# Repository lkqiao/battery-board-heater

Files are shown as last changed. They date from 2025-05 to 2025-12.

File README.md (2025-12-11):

# battery-board-heater
Subproject as part of the Stanford Student Space Initiative (SSI). This project provides the heater circuit used for the battery board of SAMWISE, the 2U CubeSat we are currently working on, to maintain optimal temperature for efficient auxiliary power supply to deployable structures, ADCS, radio, and a 12MP camera + selfie stick. 

The schematic of the heater circuit is provided in KiCAD and is integrated into the main battery board PCB and external systems of the satellite. The coordinates of the heating coil traces are automatically generated via Python script. 

Screenshot 2025-12-11 at 12 20 15 PM

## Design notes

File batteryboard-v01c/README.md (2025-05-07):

# PyCubed Battery Board

<p align="middle">
  
</p>

2S3P Li-ion battery pack for CubeSat designs.
   - Fits 18650 cells (like the LG INR18650-MJ1)
   - Meets maximum capacity requirements of common CubeSat integrators
   - Uses components with radiation testing heritage
      - R5460x2xx for protection against
         - over-charge 
         - over-discharge
         - short-circuit
         - excess discharge-current
         - excess charge-current

## Interactive Bill of Materials 🛒
- [batteryboard-v01](https://pycubed.github.io/hardware/batteryboard-v01)

<br>
<br>
<br>
<br />This work is licensed under a <a rel="license" href="http://creativecommons.org/licenses/by/4.0/">Creative Commons Attribution 4.0 International License</a>.

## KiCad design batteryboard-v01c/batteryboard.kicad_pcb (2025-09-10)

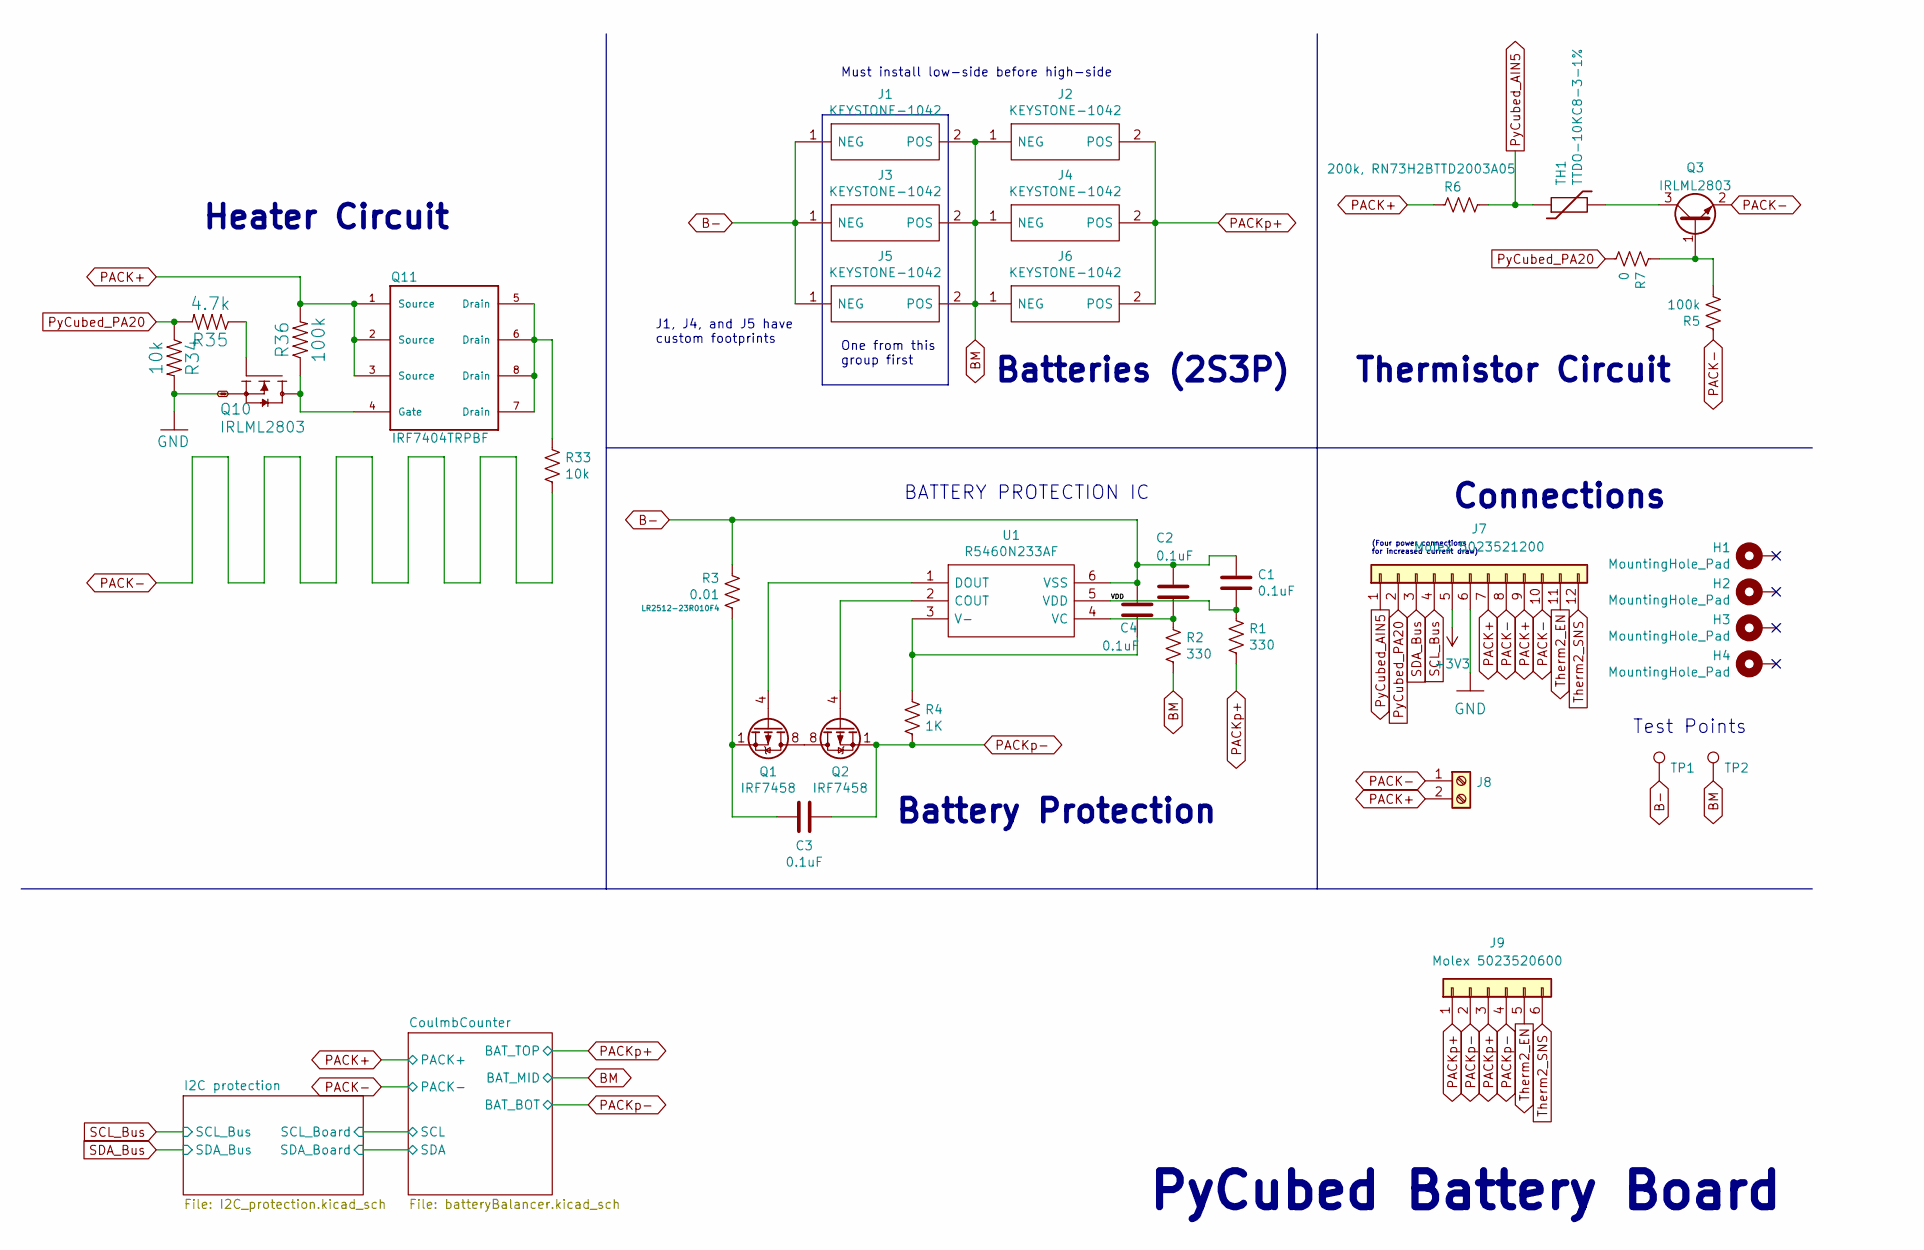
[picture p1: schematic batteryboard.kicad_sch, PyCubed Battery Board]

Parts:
C1, C2, C3, C4: 0.1uF; C_0603_1608Metric
H1, H2, H3, H4: MountingHole_Pad; MountingHole_3.2mm_M3_DIN965_PadMOD
J1: KEYSTONE-1042; Keystone_1042_J1; Manufacturer_Part_Number 1042; Mouser Part Number 534-1042
J2, J3, J6: KEYSTONE-1042; Keystone_1042; Manufacturer_Part_Number 1042; Mouser Part Number 534-1042
J4: KEYSTONE-1042; Keystone_1042_J4; Manufacturer_Part_Number 1042; Mouser Part Number 534-1042
J5: KEYSTONE-1042; Keystone_1042_J5; Manufacturer_Part_Number 1042; Mouser Part Number 534-1042
J7: Molex 5023521200; 5023521200
J8: Screw_Terminal_01x02; pheonix_2pos_screwterminal
J9: Molex 5023520600; 5023520600
Q1, Q2: IRF7458; SOIC-8_3.9x4.9mm_P1.27mm
Q3: IRLML2803; SOT-23
Q10: IRLML2803; SOT-23; Manufacturer_Part_Number MMBT2222AT
Q11: IRF7404TRPBF; Manufacturer_Part_Number NDS8434
R1, R2: 330; R_0603_1608Metric
R3: 0.01; R_2512_6332Metric
R4: 1K; R_0603_1608Metric; Manufacturer_Part_Number LR2512-23R010F4
R5, R36: 100k; R_0603_1608Metric
R6: 200k, RN73H2BTTD2003A05; R_1206_3216Metric
R7: 0; R_0603_1608Metric
R33, R34: 10k; R_0603_1608Metric
R35: 4.7k; R_0603_1608Metric
TH1: TTDO-10KC8-3-1%; R_Axial_DIN0204_L3.6mm_D1.6mm_P5.08mm_Horizontal
TP1, TP2: TestPoint; TestPoint_Loop_D1.80mm_Drill1.0mm_Beaded
U1: R5460N233AF; SOT-23-6; Manufacturer_Part_Number R5460N233AF-TR-FE; Mouser Part Number 848-R5460N233AFTRFE

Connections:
+3V3: J7.5; also elsewhere on the board
/VDD: C1.2, R1.2, U1.5 (VDD)
B-: C1.1, C2.1, C4.1, J1.1 (NEG), J3.1 (NEG), J5.1 (NEG), R3.1, TP1.1, U1.6 (VSS)
BM: J1.2 (POS), J2.1 (NEG), J3.2 (POS), J4.1 (NEG), J5.2 (POS), J6.1 (NEG), R2.1, TP2.1; also elsewhere on the board
GND: J7.6, Q10.2 (S), R34.2; also elsewhere on the board
unnamed: C3.1, Q1.1 (S), Q1.2 (S), Q1.3 (S), R3.2
unnamed: Q1.5 (D), Q1.6 (D), Q1.7 (D), Q1.8 (D), Q2.5 (D), Q2.6 (D), Q2.7 (D), Q2.8 (D)
unnamed: Q1.4 (G), U1.1 (DOUT)
unnamed: Q2.4 (G), U1.2 (COUT)
unnamed: Q3.1 (B), R5.1, R7.2
unnamed: Q3.3 (C), TH1.2
unnamed: Q10.3 (D), Q11.4 (Gate), R36.1
unnamed: Q10.1 (G), R35.1
unnamed: Q11.5 (Drain), Q11.6 (Drain), Q11.7 (Drain), Q11.8 (Drain), R33.2
unnamed: C4.2, R4.1, U1.3 (V-)
unnamed: C2.2, R2.2, U1.4 (VC)
PACK+: J7.7, J7.9, J8.2, Q11.1 (Source), Q11.2 (Source), Q11.3 (Source), R6.1, R36.2; also elsewhere on the board
PACK-: J7.8, J7.10, J8.1, Q3.2 (E), R5.2, R33.1; also elsewhere on the board
PACKp+: J2.2 (POS), J4.2 (POS), J6.2 (POS), J9.1, J9.3, R1.1; also elsewhere on the board
PACKp-: C3.2, J9.2, J9.4, Q2.1 (S), Q2.2 (S), Q2.3 (S), R4.2; also elsewhere on the board
PyCubed_AIN5: J7.1, R6.2, TH1.1
PyCubed_PA20: J7.2, R7.1, R34.1, R35.2
SCL_Bus: J7.4; also elsewhere on the board
SDA_Bus: J7.3; also elsewhere on the board
Therm2_EN: J7.11, J9.5
Therm2_SNS: J7.12, J9.6

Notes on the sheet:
Connections
(Four power connections for increased current draw)
One from this group first
PyCubed Battery Board
Batteries (2S3P)
Heater Circuit
Test Points
J1, J4, and J5 have custom footprints
Battery Protection
Must install low-side before high-side
Thermistor Circuit
BATTERY PROTECTION IC

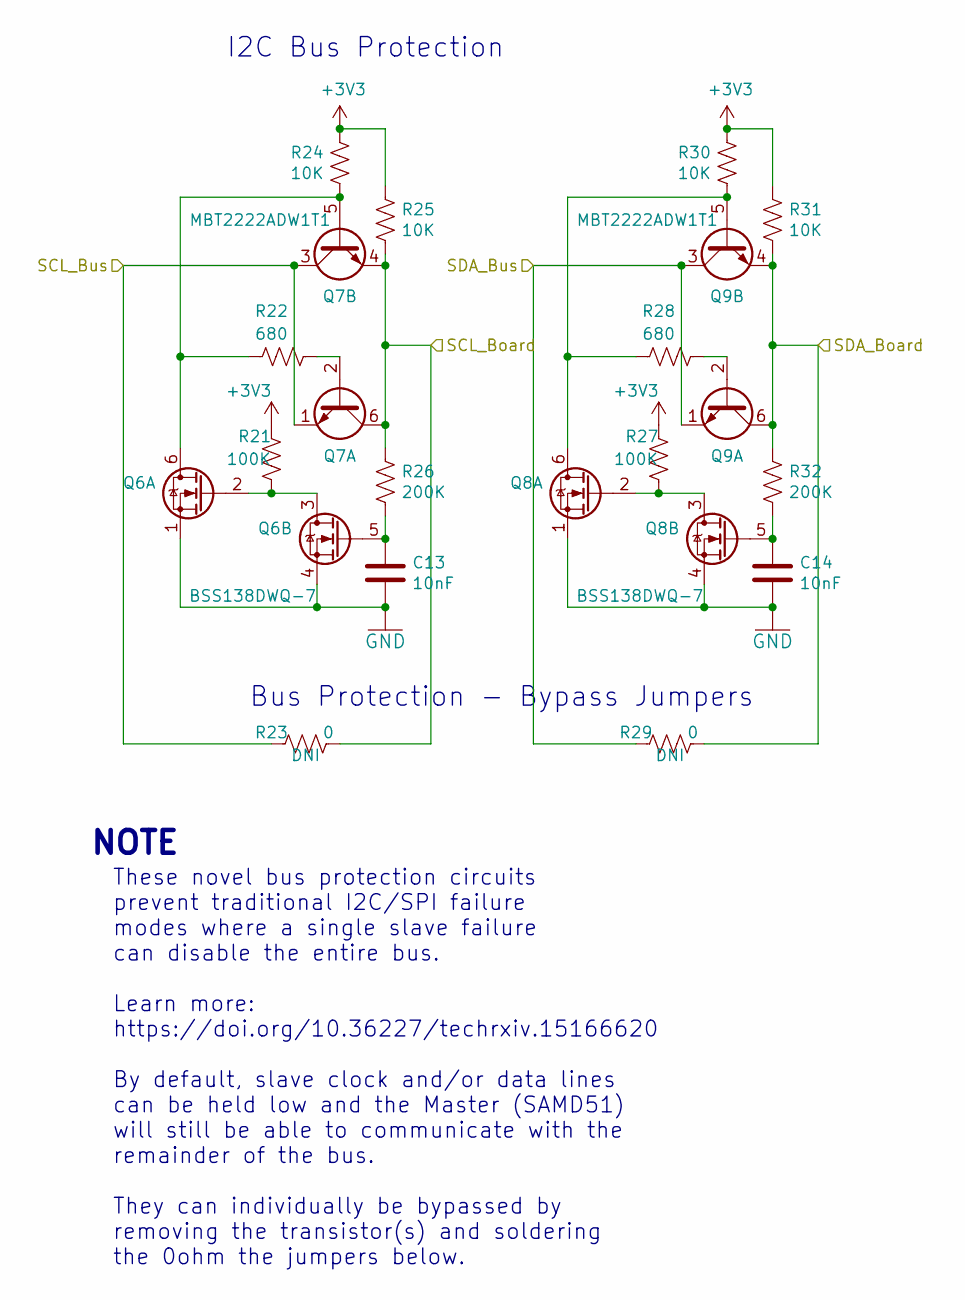
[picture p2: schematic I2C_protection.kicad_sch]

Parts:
C13, C14: 10nF; C_0603_1608Metric
Q6, Q8: BSS138DWQ-7; Manufacturer_Part_Number BSS138DWQ-7; Mouser Part Number 621-BSS138DWQ-7
Q7, Q9: MBT2222ADW1T1; SOT-363_SC-70-6; Manufacturer_Part_Number MBT2222ADW1T1G
R21, R27: 100K; R_0603_1608Metric
R22, R28: 680; R_0603_1608Metric
R23, R29: 0; R_0603_1608Metric
R24, R25, R30, R31: 10K; R_0603_1608Metric
R26, R32: 200K; R_0603_1608Metric

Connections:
+3V3: R21.1, R24.1, R25.1, R27.1, R30.1, R31.1; also elsewhere on the board
/CoulmbCounter/SCL: Q7.4 (E2), Q7.6 (C1), R23.1, R25.2, R26.1; also elsewhere on the board
/CoulmbCounter/SDA: Q9.4 (E2), Q9.6 (C1), R29.1, R31.2, R32.1; also elsewhere on the board
GND: C13.2, C14.2, Q6.1 (S2), Q6.4 (S1), Q8.1 (S2), Q8.4 (S1); also elsewhere on the board
unnamed: Q6.6 (D1), Q7.5 (B2), R22.2, R24.2
unnamed: Q6.2 (G2), Q6.3 (D2), R21.2
unnamed: C13.1, Q6.5 (G1), R26.2
unnamed: Q7.2 (B1), R22.1
unnamed: Q8.6 (D1), Q9.5 (B2), R28.2, R30.2
unnamed: Q8.2 (G2), Q8.3 (D2), R27.2
unnamed: C14.1, Q8.5 (G1), R32.2
unnamed: Q9.2 (B1), R28.1
SCL_Bus: Q7.1 (E1), Q7.3 (C2), R23.2; also elsewhere on the board
SDA_Bus: Q9.1 (E1), Q9.3 (C2), R29.2; also elsewhere on the board

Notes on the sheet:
NOTE
These novel bus protection circuits prevent traditional I2C/SPI failure modes where a single slave failure can disable the entire bus. Learn more: https://doi.org/10.36227/techrxiv.15166620 By default, slave clock and/or data lines can be held low and the Master (SAMD51) will still be able to commu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
Bus Protection - Bypass Jumpers
I2C Bus Protection

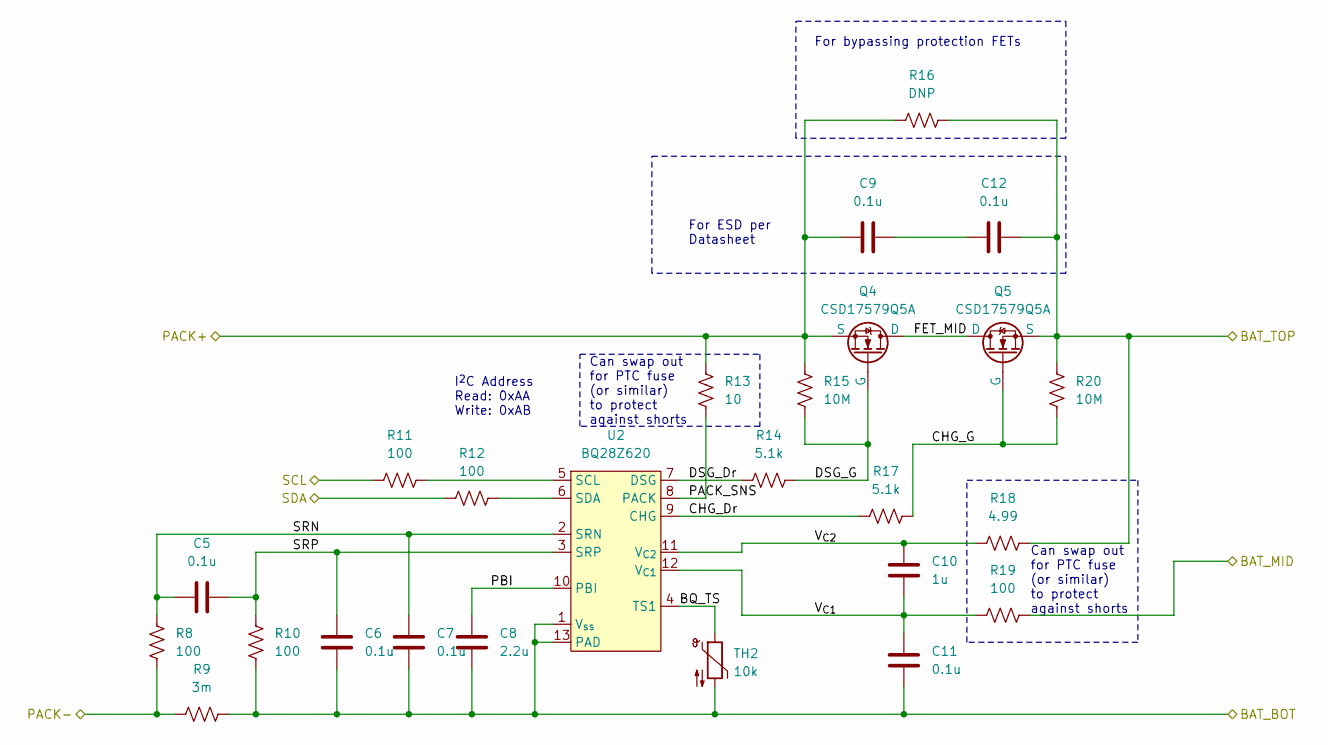
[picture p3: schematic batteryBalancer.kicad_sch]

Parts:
C5, C6, C7, C9, C11, C12: 0.1u; C_0603_1608Metric
C8: 2.2u; C_0603_1608Metric
C10: 1u; C_0603_1608Metric
Q4, Q5: CSD17579Q5A; DQJ8_NMOS_DGS
R8, R10, R11, R12, R19: 100; R_0603_1608Metric
R9: 3m; R_1206_3216Metric
R13: 10; R_0603_1608Metric
R14, R17: 5.1k; R_0603_1608Metric
R15, R20: 10M; R_0603_1608Metric
R16: DNP; R_1206_3216Metric
R18: 4.99; R_0603_1608Metric
TH2: 10k; R_Axial_DIN0204_L3.6mm_D1.6mm_P5.08mm_Horizontal
U2: BQ28Z620; VSON12_DRZ_TEX

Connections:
/CoulmbCounter/BQ_TS: TH2.1, U2.4 (TS1)
/CoulmbCounter/CHG_Dr: R17.1, U2.9 (CHG)
/CoulmbCounter/CHG_G: Q5.2 (G), R17.2, R20.2
/CoulmbCounter/DSG_Dr: R14.1, U2.7 (DSG)
/CoulmbCounter/DSG_G: Q4.2 (G), R14.2, R15.2
/CoulmbCounter/FET_MID: Q4.1 (D), Q5.1 (D)
/CoulmbCounter/PACK_SNS: R13.2, U2.8 (PACK)
/CoulmbCounter/PBI: C8.1, U2.10 (PBI)
/CoulmbCounter/SCL: R11.1; also elsewhere on the board
/CoulmbCounter/SDA: R12.1; also elsewhere on the board
/CoulmbCounter/SRN: C5.1, C7.1, R8.1, U2.2 (SRN)
/CoulmbCounter/SRP: C5.2, C6.1, R10.1, U2.3 (SRP)
/CoulmbCounter/V_{C1}: C10.2, C11.1, R19.1, U2.12 (V_{C1})
/CoulmbCounter/V_{C2}: C10.1, R18.1, U2.11 (V_{C2})
BM: R19.2; also elsewhere on the board
unnamed: C9.2, C12.1
unnamed: R11.2, U2.5 (SCL)
unnamed: R12.2, U2.6 (SDA)
PACK+: C9.1, Q4.3 (S), R13.1, R15.1, R16.1; also elsewhere on the board
PACK-: R8.2, R9.1; also elsewhere on the board
PACKp+: C12.2, Q5.3 (S), R16.2, R18.2, R20.1; also elsewhere on the board
PACKp-: C6.2, C7.2, C8.2, C11.2, R9.2, R10.2, TH2.2, U2.1 (V_{ss}), U2.13 (PAD); also elsewhere on the board

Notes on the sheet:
Can swap out for PTC fuse (or similar) to protect against shorts
For bypassing protection FETs
I^{2}C Address Read: 0xAA Write: 0xAB
For ESD per Datasheet

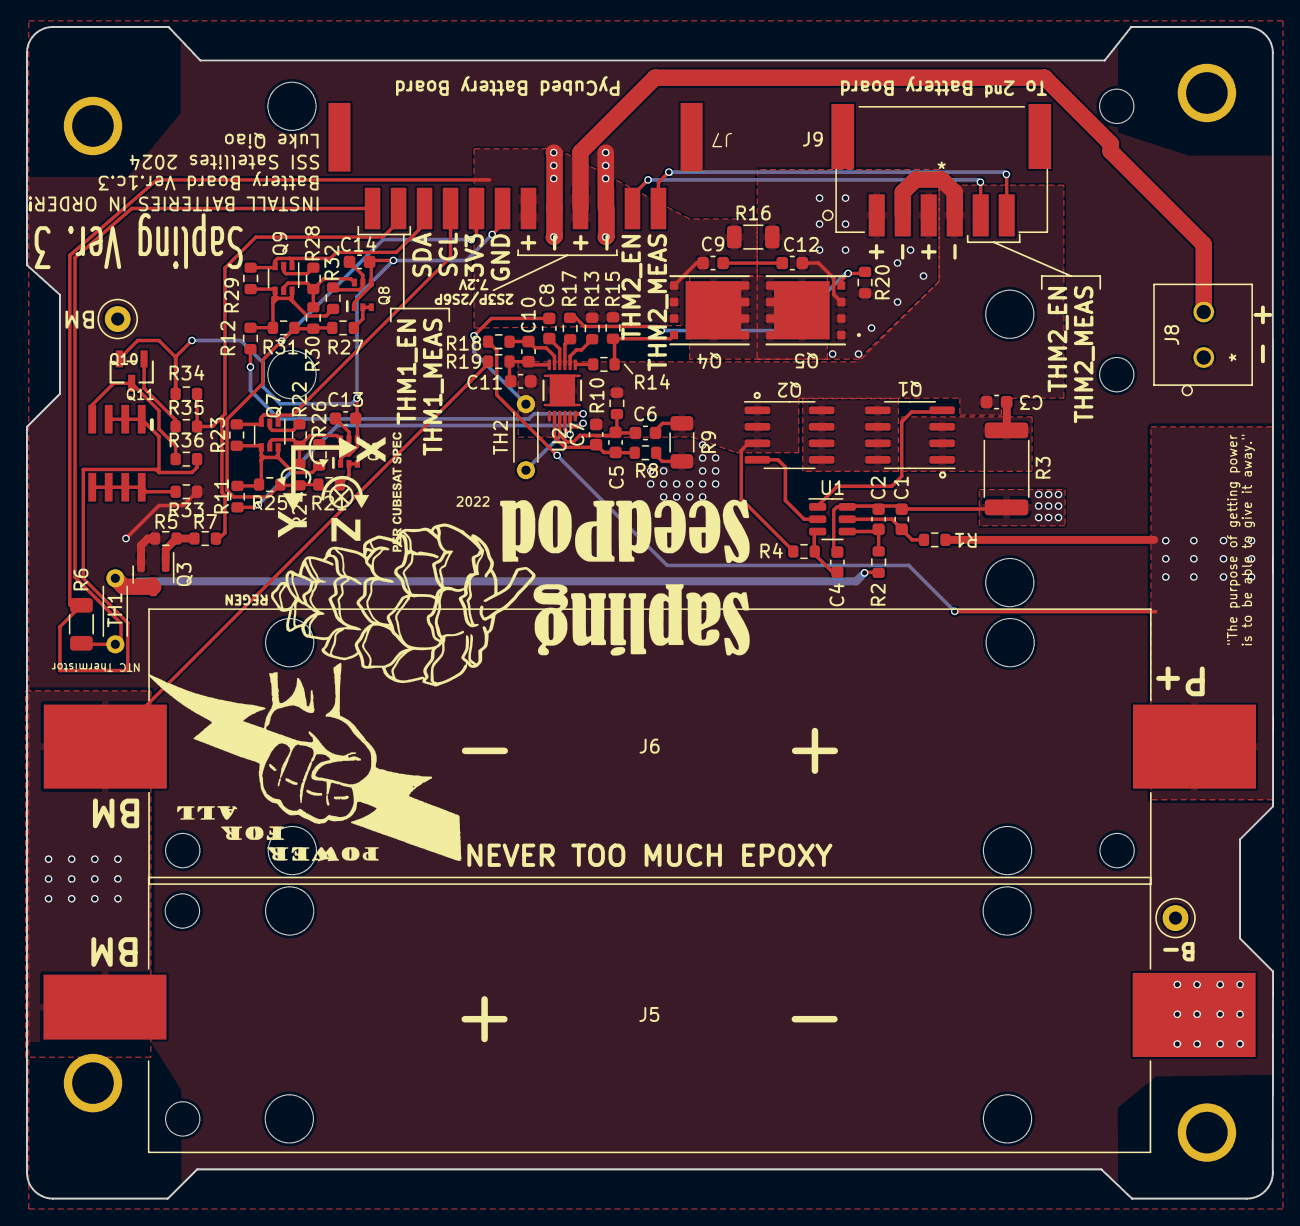
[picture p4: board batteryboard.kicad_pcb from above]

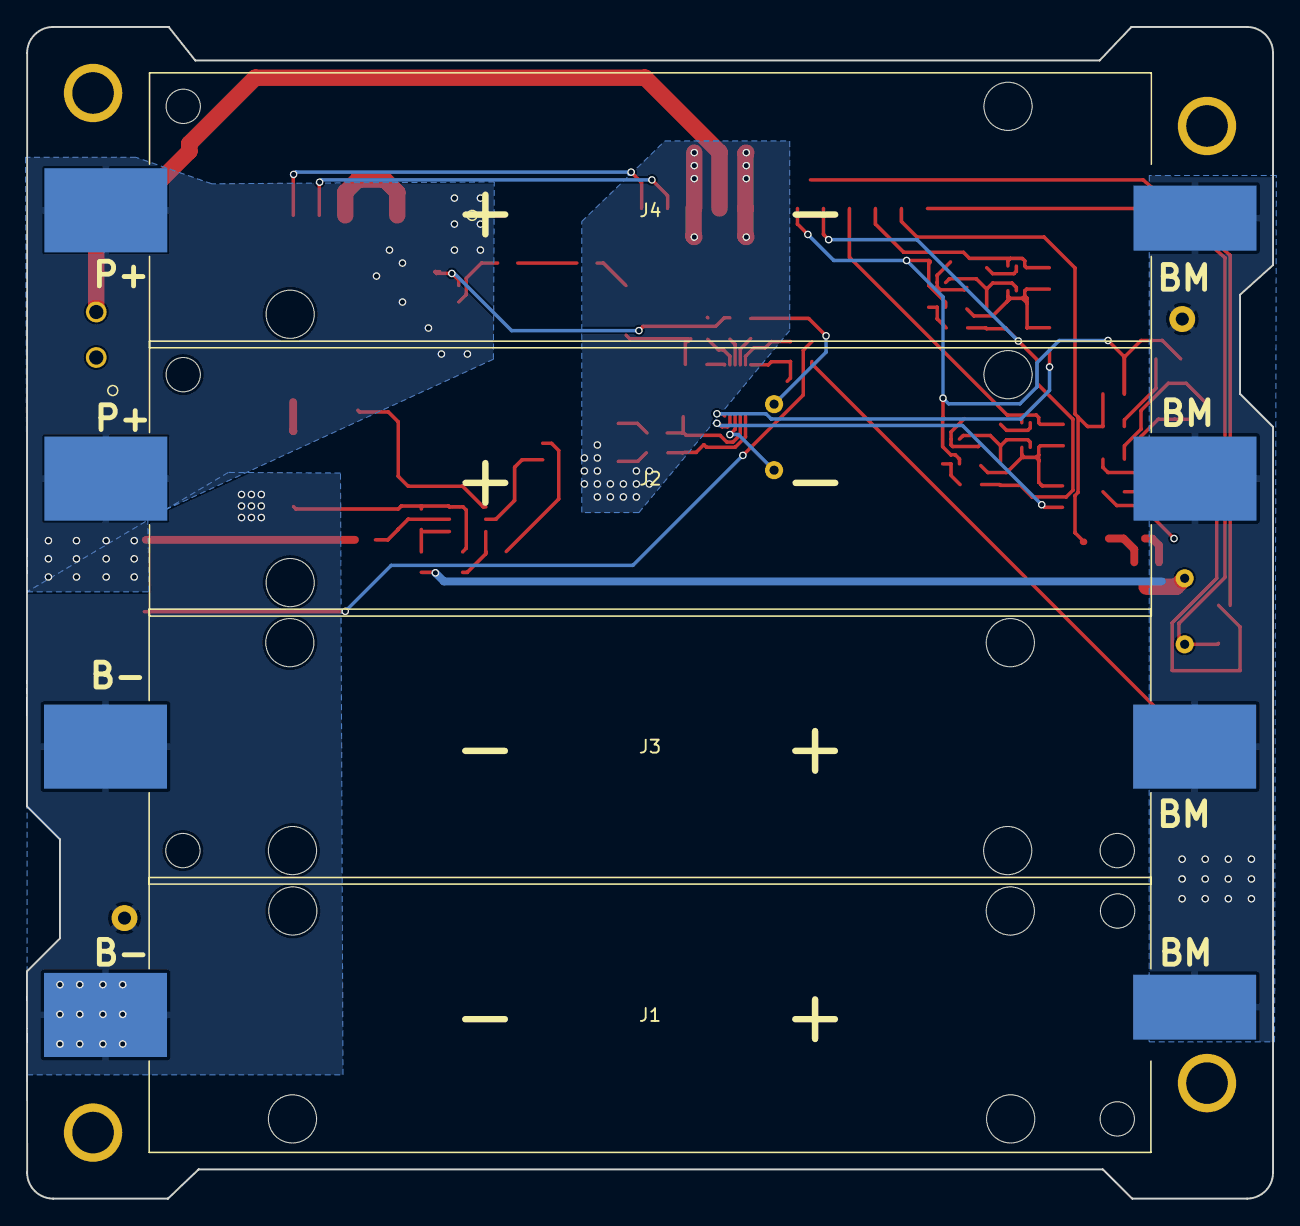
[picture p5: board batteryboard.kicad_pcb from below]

Board: 4 copper layers, 95.9 x 90.2 mm, 83 parts (5 on the bottom side), 51 nets.

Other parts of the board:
Ref**: Val**; PowerLogo
Ref**#2: Val**; SeedPodLogo
Ref**#3: Val**; XYZ_cubesat-bot

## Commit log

2023-12-08 Optimized coil shape
    [batteryboard.kicad_pcb]
2025-09-10 updated silkscreen
    [I2C_protection.kicad_sch, batteryBalancer.kicad_sch, batteryboard.kicad_pcb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]

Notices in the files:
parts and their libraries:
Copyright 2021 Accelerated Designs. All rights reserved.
